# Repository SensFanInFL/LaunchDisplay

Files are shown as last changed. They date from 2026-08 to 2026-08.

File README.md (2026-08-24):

# LaunchDisplay

LaunchDisplay is a Wi-Fi-connected ESP32-C3 launch countdown device for a 320x480 SPI TFT display. It shows the next relevant rocket launch, counts down to liftoff, tracks post-launch T+ behavior, and can be configured entirely from its built-in web setup pages.

## What It Does

- Boots on a TENSTAR ESP32-C3-Zero board and drives an Estardyn 3.5" 320x480 ST7796S SPI TFT
- Connects to Wi-Fi using a first-run onboarding portal
- Lets you configure launch filtering, timezone, sleep schedule, and level of Space Devs API access from the browser
- Shows the next launch with:
  - rocket name
  - mission or launch name
  - launch site and pad
  - scheduled date and time
  - large countdown
  - authoritative launch status
- Supports both free and paid Space Devs accounts
- Adapts polling frequency to stay within the selected account tier
- Uses a sleep schedule so the display can go dark during chosen hours

## Hardware

Verified hardware:

- Board: TENSTAR ESP32-C3-Zero
- Display: Estardyn 3.5" 320x480 ST7796S SPI TFT
- Power: USB
- Library: LovyanGFX

## Wiring

Current verified wiring:

| TFT | ESP32-C3 |
| --- | --- |
| GND | GND |
| VCC | 5V |
| SCL / SCLK | GPIO4 |
| SDA / MOSI | GPIO6 |
| RST | GPIO0 |
| DC | GPIO1 |
| CS | GPIO7 |
| BL | GPIO5 |

## STL files

STL files are in the STL directory, along with information on assembling the case.

## Display Behavior

### Normal launch view

When the device is connected and polling successfully, the screen shows:

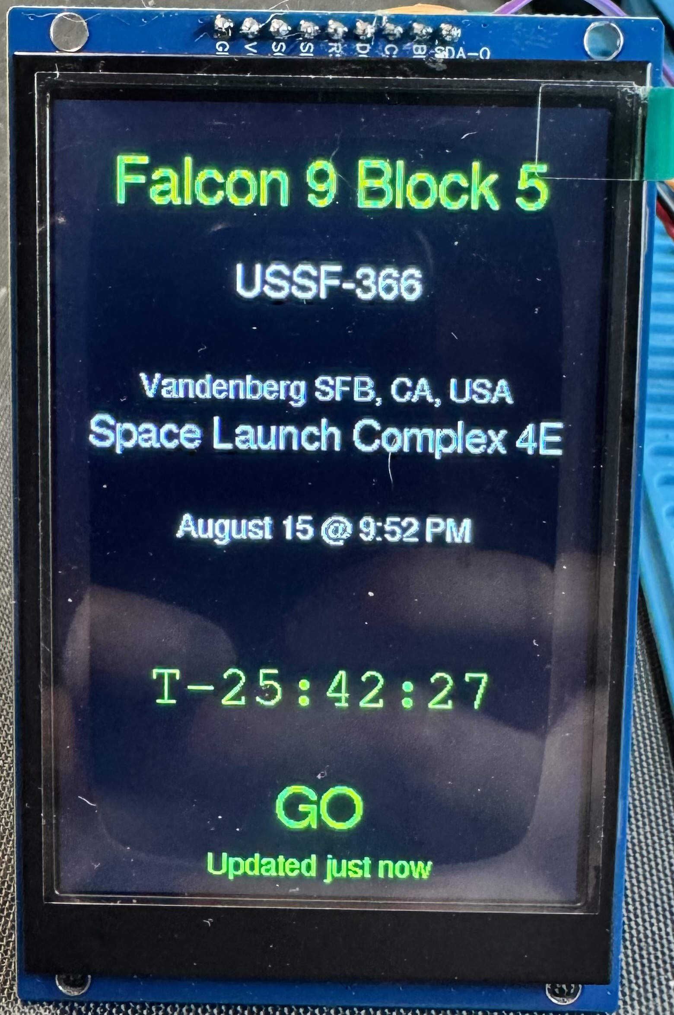
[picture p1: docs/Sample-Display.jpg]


- rocket
- mission name
- launch site
- pad
- scheduled date/time
- countdown timer
- launch status such as GO, HOLD, DELAYED, SCRUBBED, LAUNCHED, or RUD

### Startup and setup states

- If Wi-Fi is not configured yet, the device starts a setup portal named `LaunchDisplay-Setup`
- The TFT shows a QR-based setup screen during initial onboarding
- If no launch data is available yet, the display shows a standby or waiting screen
- If live fetching fails, the screen switches to an error view instead of pretending the data is current

## Getting Started

### 1. Flash the firmware

Build and flash the project with PlatformIO.

### 2. Power the device

On first boot, LaunchDisplay will try to join the saved Wi-Fi.

### 3. If Wi-Fi is not saved

The device creates a setup access point:

- SSID: `LaunchDisplay-Setup`

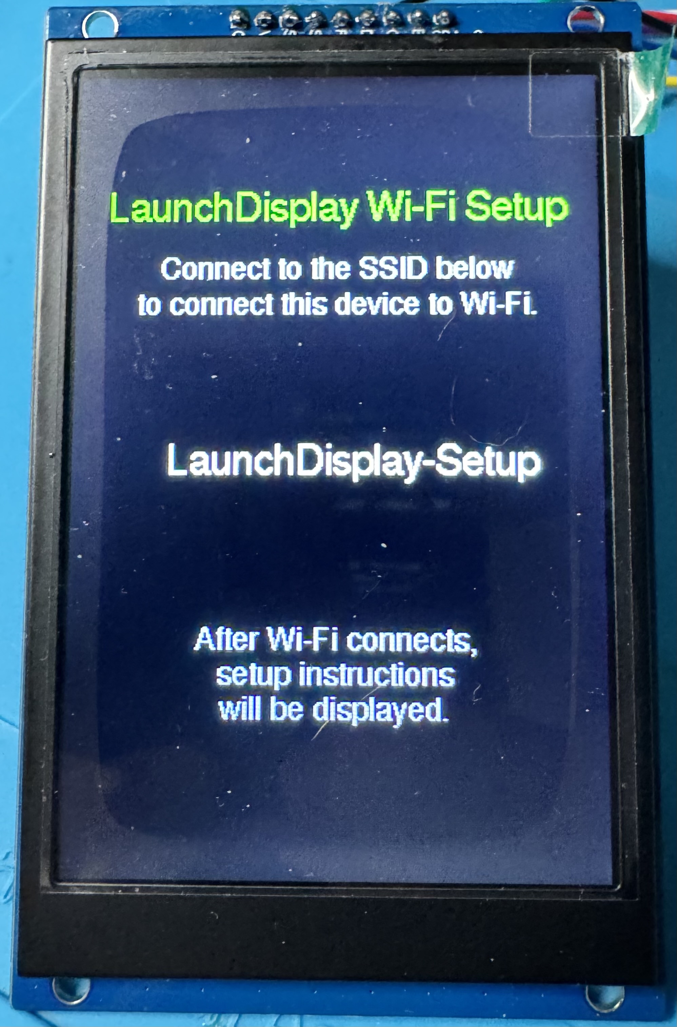
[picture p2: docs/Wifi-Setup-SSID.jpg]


- Once connected to the setup SSID, on most devices the wifi setup screen will appear on a captive portal screen. If this does not happen on your device, open a connection to http://192.168.4.1. 

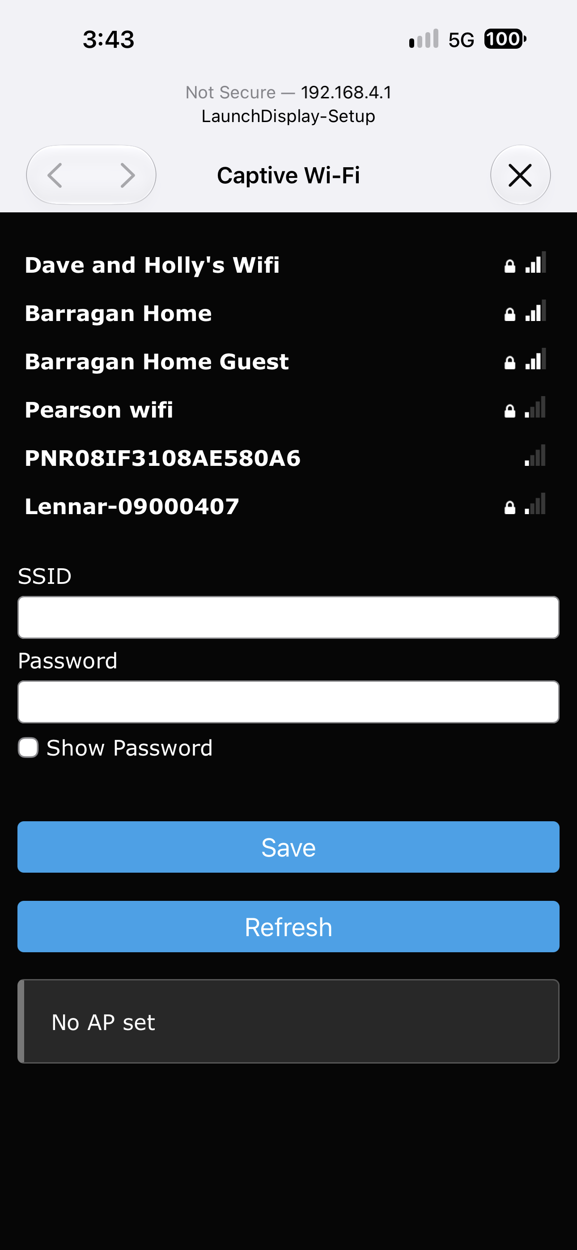
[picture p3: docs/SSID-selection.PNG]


- Select the wifi SSID you wish to connect to and enter the pre-shared key for that network. 

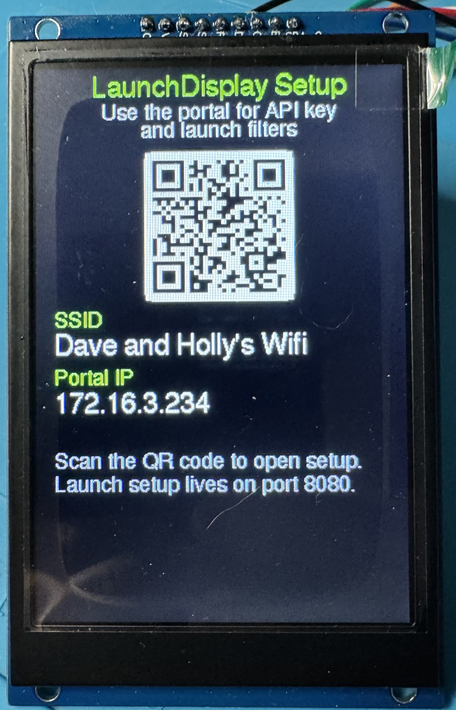
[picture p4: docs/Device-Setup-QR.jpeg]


- After the device has successfully connected to wifi, the initial setup screen is displayed. You can either scan the QR code or manually open a http connection on port 8080 to the IP address displayed on the screen to navigate to the setup portal. For example, in the pic above you would go to http://172.16.3.234:8080

### 4. Open the web setup pages

If you scan the QR code during the initial setup, you should go directly to the setup page. However, if you bookmark the setup page, you can always come back to it for access to the following options:

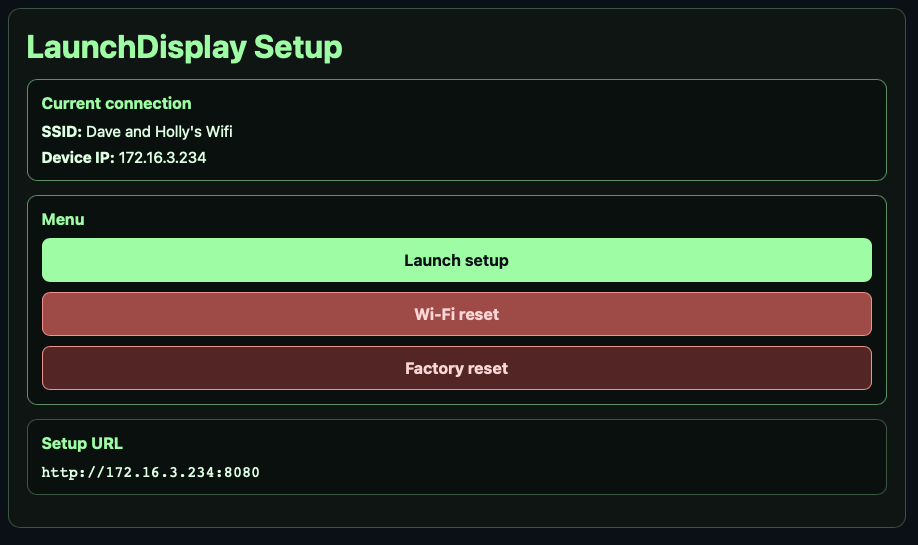
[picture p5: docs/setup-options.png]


- Settings
- Wi-Fi reset
- Factory reset

## Setup Pages

The main menu is served from the device on port `8080`.

The launch settings page is where you configure everything about what LaunchDisplay should follow and how it should behave.

## Setup Options

### API access

LaunchDisplay defaults to the free version of The Space Devs API. 

Users that have a paid membership to The Space Devs should click the box for "I have a paid Space Devs membership" to access the following additional settings:

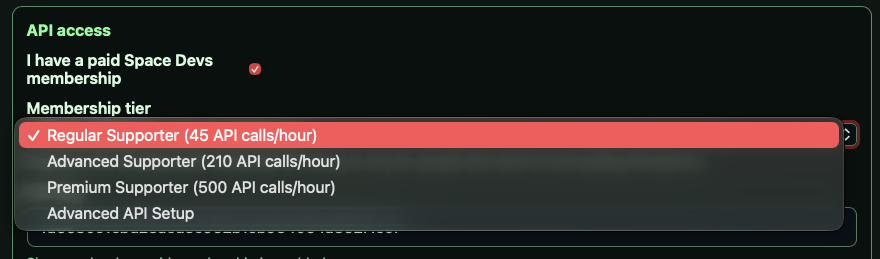
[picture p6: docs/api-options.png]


| Setting | What it does | Notes |
| --- | --- | --- |
| I have a paid Space Devs membership | Enables the paid-account path | Leave unchecked for free tier use |
| Membership tier | Chooses the paid polling model | Regular Supporter, Advanced Supporter, Premium Supporter, or Advanced API Setup |
| API key | Space Devs API key | Required for paid membership modes |

### Manually specifying polling frequency

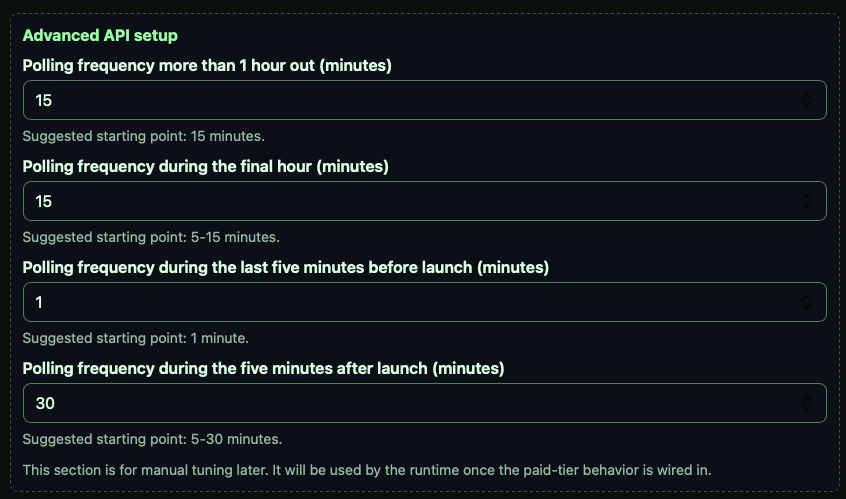
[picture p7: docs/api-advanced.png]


These fields appear when you choose `Advanced API Setup`:

| Setting | What it does | Notes |
| --- | --- | --- |
| Polling frequency more than 1 hour out (minutes) | Poll interval far from launch | Suggested starting point: 15 |
| Polling frequency during the final hour (minutes) | Poll interval closer to launch | Suggested starting point: 5-15 |
| Polling frequency during the last five minutes before launch (minutes) | Final pre-launch polling interval | Suggested starting point: 1 |
| Polling frequency during the five minutes after launch (minutes) | Early post-launch polling interval | Suggested starting point: 5-30 |

### Launch scope

| Setting | What it does | Notes |
| --- | --- | --- |
| Launch scope | Chooses the scope filter | Within a distance, Country, or Worldwide |
| Worldwide (default value) | Shows all schedule launches | No filters applied |
| Country | Filters launches by country | Used only when Launch scope is Country |
| LaunchDisplay Location | Reference location for distance-based scope | Use a city or place name, not a street address or coordinates |
| Distance units | Miles or kilometers | Used only when Launch scope is Within a distance |
| Distance | Distance from the specified location | Used only when Launch scope is Within a distance |





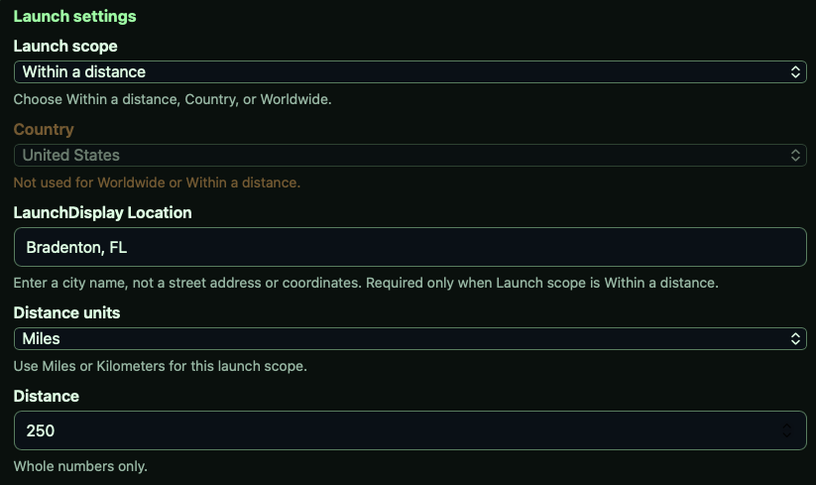
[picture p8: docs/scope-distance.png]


### Time and schedule

| Setting | What it does | Notes |
| --- | --- | --- |
| Time Zone | Display timezone | Used for launch time formatting and countdown behavior |
| Post-launch rollover | How long to keep showing T+ after launch | 15 minutes, 30 minutes, 1 hour, or 2 hours |





### Sleep schedule

| Setting | What it does | Notes |
| --- | --- | --- |
| Enable schedule | Turns scheduled sleep on or off | When enabled, the TFT sleeps during the chosen window |
| Sleep starts | Sleep start time | Time picker |
| Sleep ends | Sleep end time | Time picker |

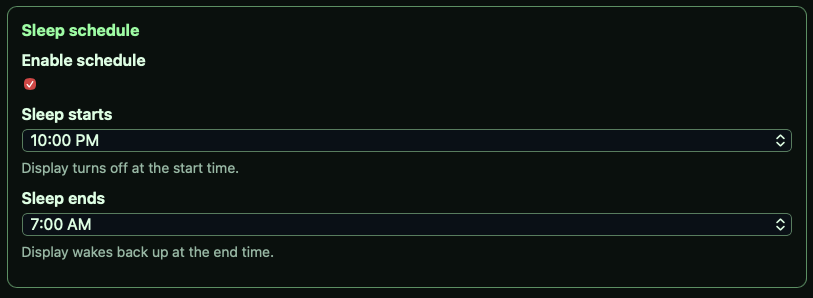
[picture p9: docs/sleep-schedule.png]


## Polling Behavior

LaunchDisplay intentionally changes how often it polls depending on how close the launch is.

The goal is to:

- stay within the account tier limits
- poll more often when launch time is near
- back off after launch
- avoid hammering the API with unnecessary requests

If the API returns a rate-limit or transient network error, the device backs off and tries again later.

## Launch Data

LaunchDisplay uses Space Devs Launch Library data to determine the next launch.

The display is built around the idea that the data on-screen should be authoritative:

- scheduled launch time comes from the API
- T-minus counts down to that launch time
- after launch, the device can show T+ for a configurable rollover period
- if a launch later changes to HOLD, DELAYED, SCRUBBED, or RUD, the screen should reflect that instead of pretending the launch happened

## Troubleshooting

### The SSID does not appear

- Make sure the ESP32 is powered and booting
- Check the serial console for the Wi-Fi setup portal message
- If you recently changed Wi-Fi settings, confirm the device restarted cleanly

### The setup page keeps coming back

- Check whether the device is still unconfigured
- Verify that Wi-Fi settings were saved successfully
- Clear browser autofill or try a private window if the browser is restoring old form state

### The display is blank or inverted

- Re-check the TFT wiring against the wiring table
- Confirm the backlight pin is connected correctly
- Verify that the display type in `include/DisplayConfig.h` matches the actual panel

### The screen shows a fetch error

- Check Wi-Fi
- Check the API key if you are on a paid tier
- Watch for rate-limit messages in the serial log
- If the API is temporarily overloaded or rate-limited, wait and try again

### The countdown looks wrong

- Confirm the timezone setting
- Confirm the launch scope
- Confirm that the launch data being shown is the correct filtered result for your location and account tier

## Development Notes

- Settings are stored on-device and do not require reflashing for normal configuration changes
- The display and web setup are intentionally separated so launch selection can be changed without touching the firmware
- The firmware keeps a simple appliance-style workflow: flash once, configure from the browser, then use it like a product

## License

MIT

## Roadmap

Keep in mind that not all ESP32's are the same dimensions as the one I used, so you will most likely need to adjust things to hold your ESP32 properly.

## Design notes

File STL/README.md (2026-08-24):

STLs are oriented for printing. 

## Recommended print settings:
- 3 walls
- 3 layers top and bottom
- 20% infill
- Organic/tree supports

## Hardware needed
- (4) M3 threaded inserts
- (4) M3x6 screws. Cap head screws look nice on it
- (4) M2.5x8 screws
- (4) M2.5 nuts

## How to assemble
### Step 1

Install the threaded inserts into the holes for them on the back

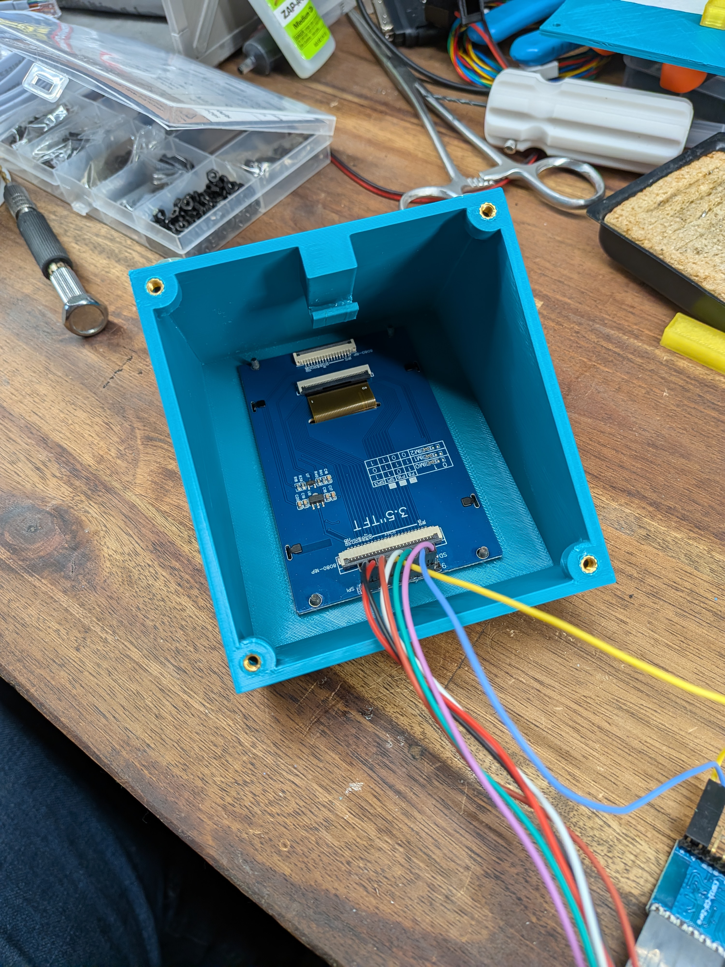
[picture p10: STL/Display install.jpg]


Glue the bracket to the ESP32 holder as shown. Cyanoacrylate glue will work fine. 

- Note: the bracket supplied in the STLs is properly sized. Glue the long side of the bracket to the ESP32 holder, butted against the bottom.
- The bracket should set approximately 3mm above the top side of the ESP32 holder.

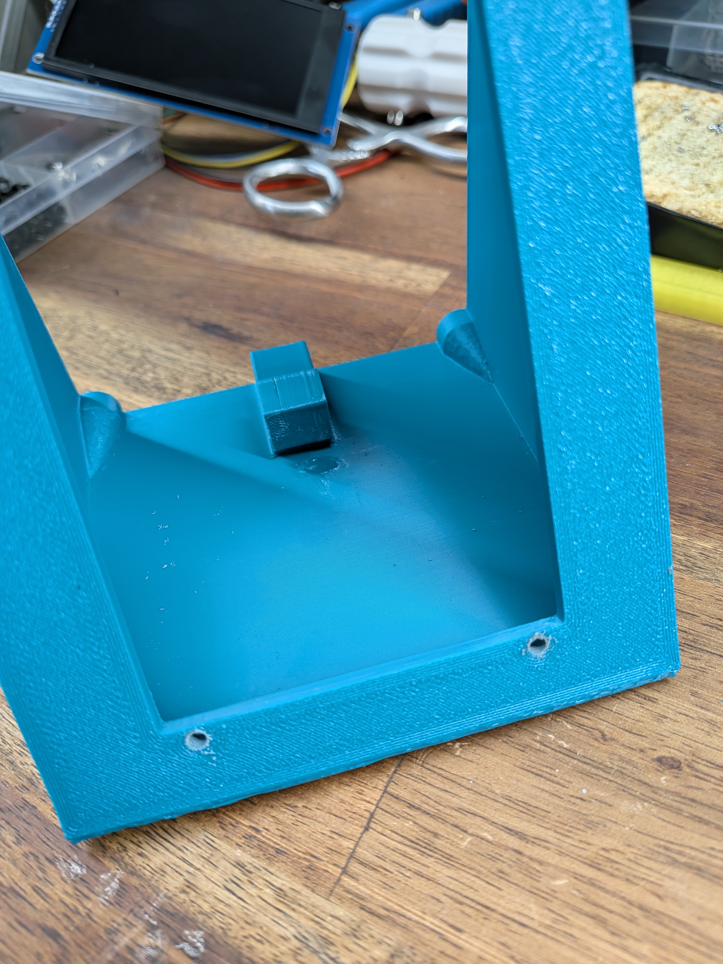
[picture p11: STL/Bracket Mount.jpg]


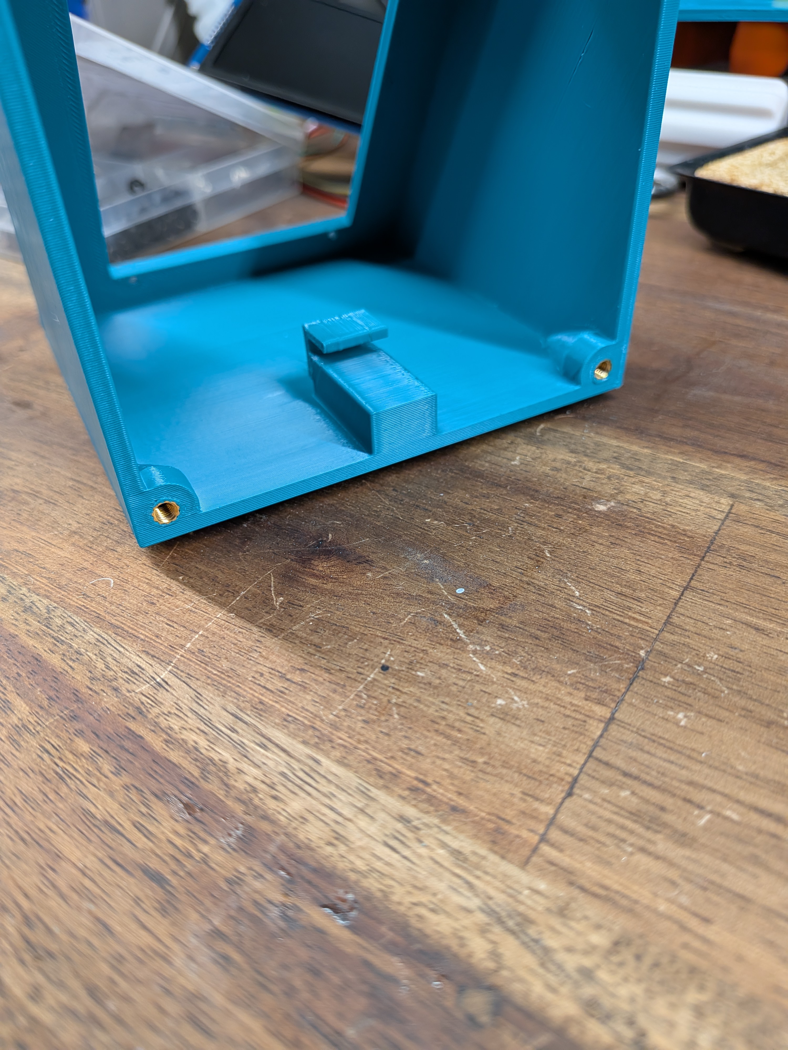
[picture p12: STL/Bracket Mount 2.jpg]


Depending on printer tolerance, you may need to drill the holes around the display opening out to 2.5mm

Install the M2.5x8 screws and install the display using the M2.5 nuts.
* The wrench STL supplied is sized such that you should be able to insert the nut, set it on the bottom of the case and slide it in to help with installing the lower nuts. You can do them by hand, but they're difficult to install.



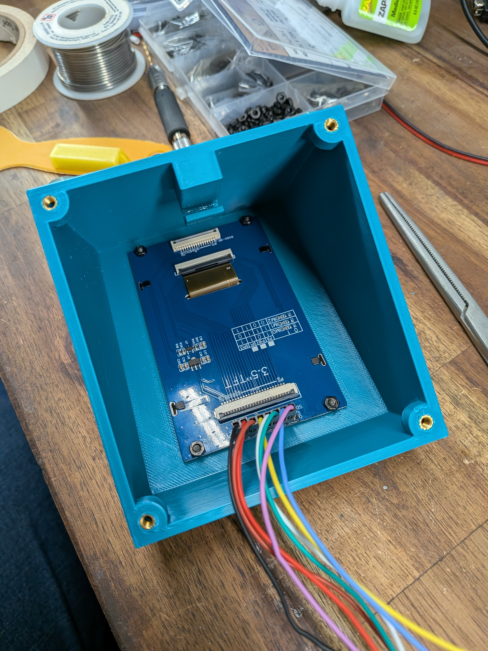
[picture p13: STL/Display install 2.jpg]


Place the ESP32 controller on the holder, with the rear of the ESP32 under the bracket that you installed earlier. The bracket keeps the rear of the controller in place, and works with the nubs on the back panel to position it such that the power cable can be plugged into it.

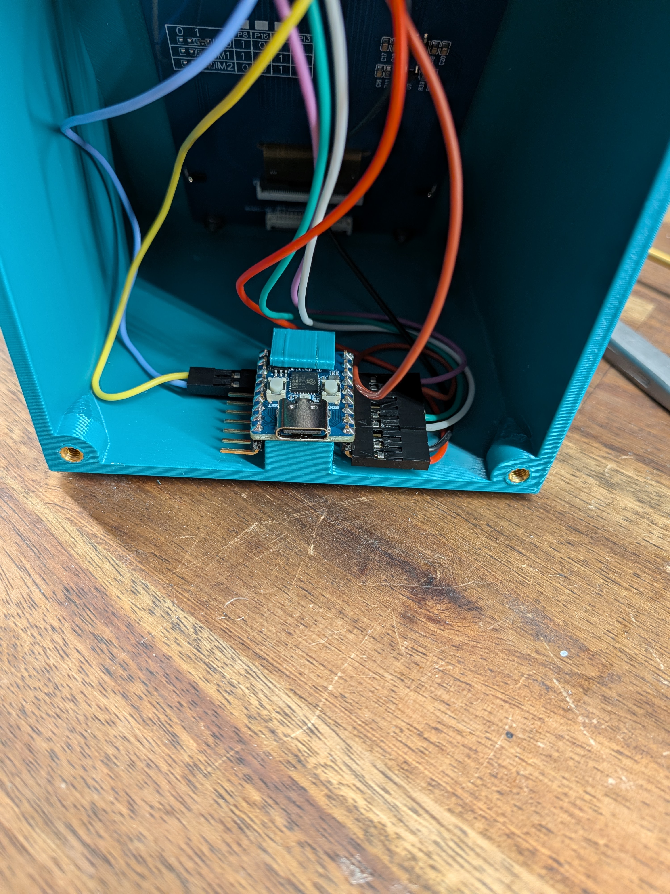
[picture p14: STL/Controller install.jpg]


Finally, install the back panel with the M3x6 screws

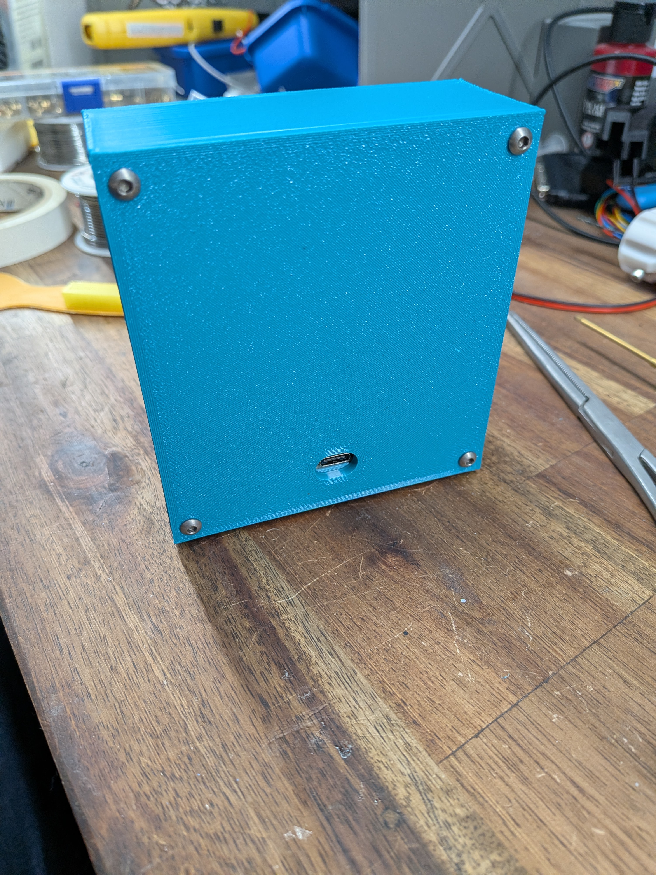
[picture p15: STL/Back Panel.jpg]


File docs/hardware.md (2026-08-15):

# LaunchDisplay Hardware Notes

This note captures the verified hardware combination for the current LaunchDisplay bring-up.

## Verified Setup

- Board: TENSTAR ESP32-C3-Zero Mini Development Board
- MCU: ESP32-C3
- Display: Estardyn 3.5" 320x480 ST7796S SPI TFT module
- Display library: LovyanGFX
- Power: USB

## Working Pin Map

| TENSTAR ESP32-C3-Zero Mini | TFT |
| --- | --- |
| `GPIO4` | `SCL` / `SCLK` |
| `GPIO6` | `SDA` / `MOSI` |
| `GPIO7` | `CS` |
| `GPIO1` | `DC` |
| `GPIO0` | `RST` |
| `GPIO5` | `BL` |
| `5V` | `VCC` |
| `GND` | `GND` |

## Notes

- `GPIO2`, `GPIO8`, and `GPIO9` are strapping pins on the ESP32-C3, so they are left unused.
- `GPIO18` and `GPIO19` are associated with USB serial/JTAG on the C3 family, so they are also left unused.
- `GPIO20` and `GPIO21` are left free so the default serial path stays simple.

## Wiring diagrams

- [`docs/wiring-schematic.svg`](./wiring-schematic.svg)
- [`docs/wiring-breadboard.svg`](./wiring-breadboard.svg)

## Bring-Up Result

The current firmware successfully:

- connects to Wi-Fi using the reused setup flow,
- initializes the TFT display,
- and renders the LaunchDisplay standby / launch screen.

That makes this a verified baseline for future launch data integration work.

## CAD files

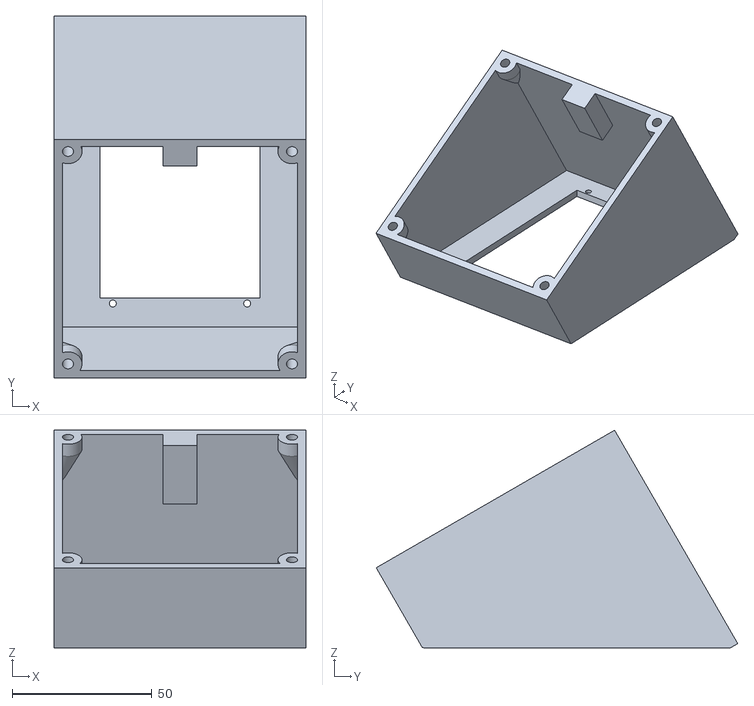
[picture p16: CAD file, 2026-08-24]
STL/Body.stl
90.0 x 129.1 x 77.7

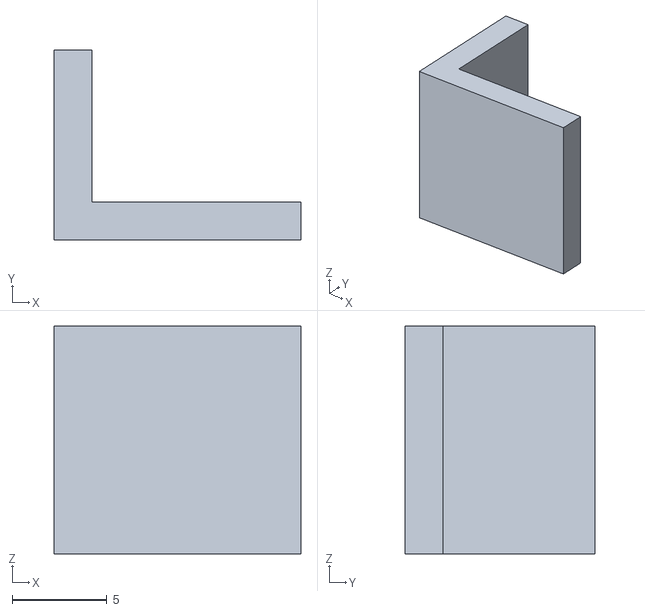
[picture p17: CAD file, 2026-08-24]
STL/Bracket.stl
13.0 x 10.0 x 12.0

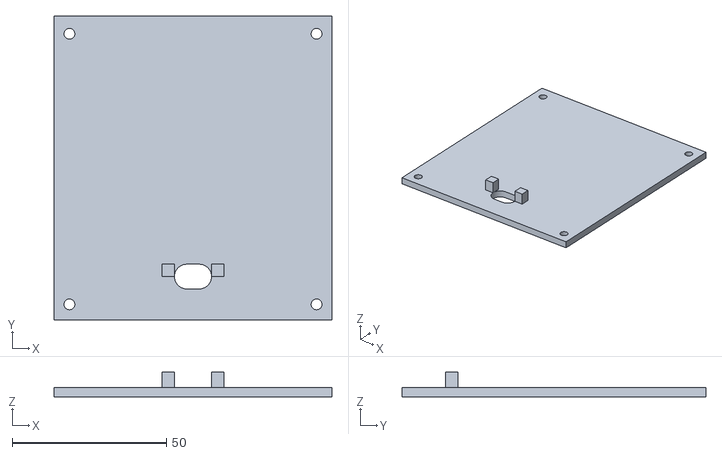
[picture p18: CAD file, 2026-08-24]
STL/Back Panel.stl
90.0 x 98.3 x 8.00

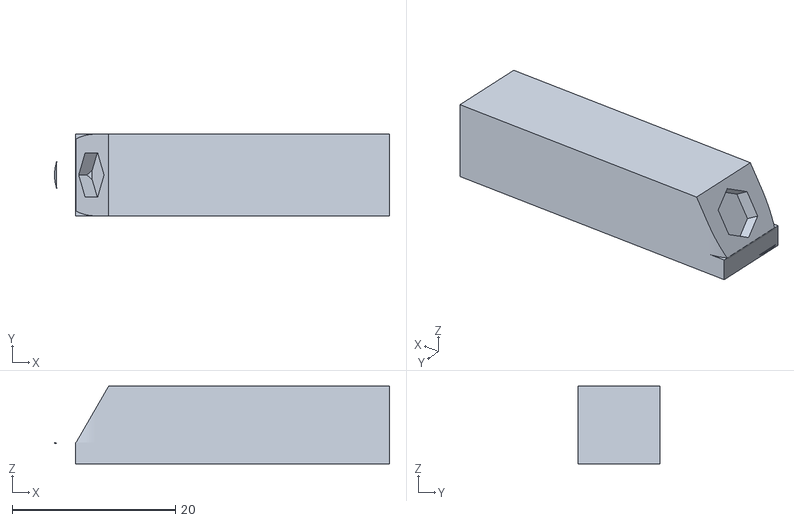
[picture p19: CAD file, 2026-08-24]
STL/Wrench.stl
41.0 x 10.0 x 9.50

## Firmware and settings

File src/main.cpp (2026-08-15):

#include <Arduino.h>
#include <array>
#include <time.h>
#include <WiFi.h>
#include <WiFiManager.h>
#include <WebServer.h>

#include "DisplayConfig.h"
#include "LGFX.h"
#include "LaunchDisplayApp.h"
#include "LaunchLibraryClient.h"
#include "LaunchSettings.h"
#include "WiFiManagerHelpers.h"

static void LoadSleepSchedule(const LaunchSettings &settings);

enum class LaunchScreenMode
{
  Setup,
  Preview,
};

extern LaunchScreenMode screenMode;
extern bool screenNeedsRedraw;
extern LaunchLibraryClient launchLibraryClient;

namespace
{
struct LaunchPollState
{
  LaunchPreviewState preview;
  bool hasPreview = false;
  unsigned long nextPollAtMs = 0;
  std::array<unsigned long, 15> pollHistory{};
  size_t pollHistoryCount = 0;
  String lastError;
};

LaunchPollState launchPollState;
bool pendingScopeVerification = false;
LaunchSettings activeSettings;
bool displaySleeping = false;
int sleepStartMinutes = 22 * 60;
int sleepEndMinutes = 7 * 60;
bool sleepScheduleEnabled = false;

struct SelectOption
{
  const char *value;
  const char *label;
};

constexpr SelectOption kLaunchScopeOptions[] = {
    {"within_distance", "Within a distance"},
    {"country", "Country"},
    {"worldwide", "Worldwide"},
};

constexpr SelectOption kDistanceUnitOptions[] = {
    {"miles", "Miles"},
    {"kilometers", "Kilometers"},
};

constexpr SelectOption kPostLaunchOptions[] = {
    {"15 minutes", "15 minutes"},
    {"30 minutes", "30 minutes"},
    {"1 hour", "1 hour"},
    {"2 hours", "2 hours"},
};

constexpr SelectOption kApiTierOptions[] = {
    {"regular_supporter", "Regular Supporter (45 API calls/hour)"},
    {"advanced_supporter", "Advanced Supporter (210 API calls/hour)"},
    {"premium_supporter", "Premium Supporter (500 API calls/hour)"},
    {"advanced_api_setup", "Advanced API Setup"},
};

constexpr SelectOption kSleepTimeOptions[] = {
    {"21:00", "9:00 PM"},
    {"22:00", "10:00 PM"},
    {"23:00", "11:00 PM"},
    {"00:00", "12:00 AM"},
    {"01:00", "1:00 AM"},
    {"06:00", "6:00 AM"},
    {"07:00", "7:00 AM"},
    {"08:00", "8:00 AM"},
};

constexpr SelectOption kCountryOptions[] = {
    {"United States", "United States"},
    {"Canada", "Canada"},
    {"Mexico", "Mexico"},
    {"United Kingdom", "United Kingdom"},
    {"Brazil", "Brazil"},
    {"Spain", "Spain"},
    {"France", "France"},
    {"Germany", "Germany"},
    {"Italy", "Italy"},
    {"Australia", "Australia"},
    {"Japan", "Japan"},
    {"New Zealand", "New Zealand"},
};

constexpr SelectOption kTimeZoneOptions[] = {
    {"UTC", "UTC"},
    {"America/New_York", "America/New_York"},
    {"America/Chicago", "America/Chicago"},
    {"America/Denver", "America/Denver"},
    {"America/Los_Angeles", "America/Los_Angeles"},
    {"America/Phoenix", "America/Phoenix"},
    {"Europe/London", "Europe/London"},
    {"Europe/Paris", "Europe/Paris"},
    {"Asia/Tokyo", "Asia/Tokyo"},
    {"Australia/Sydney", "Australia/Sydney"},
};

String HtmlEscape(const String &input)
{
  String output;
  output.reserve(input.length() + 8);
  for (size_t i = 0; i < input.length(); ++i)
  {
    const char c = input[i];
    switch (c)
    {
    case '&':
      output += F("&amp;");
      break;
    case '<':
      output += F("&lt;");
      break;
    case '>':
      output += F("&gt;");
      break;
    case '"':
      output += F("&quot;");
      break;
    case '\'':
      output += F("&#39;");
      break;
    default:
      output += c;
      break;
    }
  }
  return output;
}

String RenderSelectOptions(const String &currentValue, const SelectOption *options, size_t optionCount)
{
  String html;
  bool matched = false;
  for (size_t i = 0; i < optionCount; ++i)
  {
    if (currentValue == options[i].value)
    {
      matched = true;
      break;
    }
  }

  if (!matched && currentValue.length())
  {
    html += F("<option value='");
    html += HtmlEscape(currentValue);
    html += F("' selected>");
    html += HtmlEscape(currentValue);
    html += F("</option>");
  }

  for (size_t i = 0; i < optionCount; ++i)
  {
    html += F("<option value='");
    html += HtmlEscape(options[i].value);
    html += F("'");
    if (currentValue == options[i].value)
    {
      html += F(" selected");
    }
    html += F(">");
    html += HtmlEscape(options[i].label);
    html += F("</option>");
  }

  return html;
}

String RenderSelectField(const char *name, const char *label, const String &currentValue, const SelectOption *options, size_t optionCount, const String &hint = String())
{
  String html;
  html += F("<label class='field'>");
  html += F("<span>");
  html += HtmlEscape(label);
  html += F("</span>");
  html += F("<select name='");
  html += HtmlEscape(name);
  html += F("'>");
  html += RenderSelectOptions(currentValue, options, optionCount);
  html += F("</select>");
  if (hint.length())
  {
    html += F("<div class='hint'>");
    html += HtmlEscape(hint);
    html += F("</div>");
  }
  html += F("</label>");
  return html;
}

String RenderTextField(const char *name, const char *label, const String &value, const char *placeholder, const String &hint = String())
{
  String html;
  html += F("<label class='field'>");
  html += F("<span>");
  html += HtmlEscape(label);
  html += F("</span>");
  html += F("<input name='");
  html += HtmlEscape(name);
  html += F("' type='text' value='");
  html += HtmlEscape(value);
  html += F("' placeholder='");
  html += HtmlEscape(placeholder);
  html += F("'>");
  if (hint.length())
  {
    html += F("<div class='hint'>");
    html += HtmlEscape(hint);
    html += F("</div>");
  }
  html += F("</label>");
  return html;
}

String RenderTimeField(const char *name, const char *label, const String &value, const String &hint = String())
{
  String html;
  html += F("<label class='field'>");
  html += F("<span>");
  html += HtmlEscape(label);
  html += F("</span>");
  html += F("<input name='");
  html += HtmlEscape(name);
  html += F("' type='time' value='");
  html += HtmlEscape(value);
  html += F("'>");
  if (hint.length())
  {
    html += F("<div class='hint'>");
    html += HtmlEscape(hint);
    html += F("</div>");
  }
  html += F("</label>");
  return html;
}

String RenderNumberField(const char *name, const char *label, const String &value, const char *minValue, const char *maxValue, const String &hint = String())
{
  String html;
  html += F("<label class='field'>");
  html += F("<span>");
  html += HtmlEscape(label);
  html += F("</span>");
  html += F("<input name='");
  html += HtmlEscape(name);
  html += F("' type='number' min='");
  html += HtmlEscape(minValue);
  html += F("' max='");
  html += HtmlEscape(maxValue);
  html += F("' value='");
  html += HtmlEscape(value);
  html += F("'>");
  if (hint.length())
  {
    html += F("<div class='hint'>");
    html += HtmlEscape(hint);
    html += F("</div>");
  }
  html += F("</label>");
  return html;
}

String RenderCheckboxField(const char *name, const char *label, bool checked, const String &hint = String())
{
  String html;
  html += F("<label class='field inline'>");
  html += F("<span>");
  html += HtmlEscape(label);
  html += F("</span><input name='");
  html += HtmlEscape(name);
  html += F("' type='checkbox'");
  if (checked)
  {
    html += F(" checked");
  }
  html += F("></label>");
  if (hint.length())
  {
    html += F("<div class='hint'>");
    html += HtmlEscape(hint);
    html += F("</div>");
  }
  return html;
}

String BuildSetupPage(const LaunchSettings &settings, const String &wifiSsid, const String &deviceIp, bool saved = false, const String &bannerMessage = String(), bool bannerIsError = false)
{
  const String setupUrl = String("http://") + deviceIp + ":8080/launch-setup";
  const bool wifiReady = wifiSsid.length() > 0 && deviceIp.length() > 0 && deviceIp != "0.0.0.0";
  const bool launchConfigured = settings.configured;

  String html;
  html.reserve(12000);
  html += F("<!doctype html><html><head><meta name='viewport' content='width=device-width, initial-scale=1'>");
  html += F("<title>LaunchDisplay Setup</title><style>");
  html += F("body{margin:0;padding:18px;background:#081017;color:#d6ffe1;font-family:system-ui,-apple-system,Segoe UI,Roboto,sans-serif;}");
  html += F("main{max-width:860px;margin:0 auto;border:1px solid #30543f;background:#0d1512;padding:18px;border-radius:12px;}");
  html += F("h1{margin:0 0 10px;font-size:2rem;color:#7cff9a;}");
  html += F(".section{border:1px solid #315844;background:#09100d;padding:14px;border-radius:10px;margin:14px 0;}");
  html += F(".section.green{border-color:#4b915f;}");
  html += F(".section.orange{border-color:#9a6b32;}");
  html += F(".section.red{border-color:#a44;}");
  html += F(".section-title{font-weight:700;color:#7cff9a;margin-bottom:10px;}");
  html += F(".section.orange .section-title{color:#ffb04c;}");
  html += F(".section.red .section-title{color:#ff8b8b;}");
  html += F(".field{display:flex;flex-direction:column;gap:6px;margin:12px 0;}");
  html += F(".field.inline{flex-direction:row;align-items:center;justify-content:space-between;gap:12px;}");
  html += F(".field span{font-weight:600;color:#d6ffe1;}");
  html += F(".field input,.field select{width:100%;box-sizing:border-box;background:#081017;color:#d6ffe1;border:1px solid #4d7d5b;padding:10px 12px;border-radius:8px;font-size:1rem;}");
  html += F(".field.dimmed{opacity:0.45;}");
  html += F(".field.active span{color:#7cff9a;}");
  html += F(".field.inactive span{color:#ffb04c;}");
  html += F(".hidden{display:none;}");
  html += F(".subsection{border:1px dashed #315844;background:#081017;padding:12px;border-radius:8px;margin:12px 0;}");
  html += F(".subsection-title{font-weight:700;color:#7cff9a;margin-bottom:8px;}");
  html += F(".hint{font-size:0.88rem;color:#90b9a3;line-height:1.35;}");
  html += F(".status{display:grid;grid-template-columns:1fr;gap:8px;font-size:0.95rem;color:#d6ffe1;}");
  html += F(".button-row{display:flex;flex-wrap:wrap;gap:10px;align-items:center;}");
  html += F(".button{display:inline-block;text-decoration:none;padding:10px 14px;border-radius:8px;border:1px solid #4d7d5b;background:#1d3f2d;color:#d6ffe1;font-weight:700;}");
  html += F(".button.danger{border-color:#a44;background:#432;}");
  html += F(".button.save{background:#7cff9a;color:#081017;border-color:#7cff9a;}");
  html += F(".divider{height:1px;background:#315844;margin:14px 0;}");
  html += F(".note{font-size:0.9rem;color:#90b9a3;line-height:1.4;}");
  html += F("code{background:#081017;padding:2px 6px;border-radius:6px;border:1px solid #315844;}");
  html += F("</style></head><body><main>");
  html += F("<h1>LaunchDisplay Setup</h1>");

  if (bannerMessage.length())
  {
    html += F("<div class='section ");
    html += bannerIsError ? F("red") : F("green");
    html += F("'><div class='section-title'>");
    html += bannerIsError ? F("Needs attention") : F("Verified");
    html += F("</div><div class='note'>");
    html += HtmlEscape(bannerMessage);
    html += F("</div></div>");
  }
  else if (saved)
  {
    html += F("<div class='section green'><div class='section-title'>Saved</div><div class='note'>Launch settings were saved successfully.</div></div>");
  }

  html += F("<div class='button-row'><a href='http://");
  html += HtmlEscape(deviceIp);
  html += F(":8080/' class='button' style='background:#1d3f2d;color:#d6ffe1;border:1px solid #4d7d5b'>Back To Main Menu</a></div>");

  html += F("<div class='section ");
  html += wifiReady ? F("green") : F("orange");
  html += F("'><div class='section-title'>Current connection</div><div class='status'>");
  html += F("<div><strong>SSID:</strong> ");
  html += wifiSsid.length() ? HtmlEscape(wifiSsid) : F("Not connected");
  html += F("</div><div><strong>Device IP:</strong> ");
  html += HtmlEscape(deviceIp);
  html += F("</div><div><strong>Setup URL:</strong> <code>");
  html += HtmlEscape(setupUrl);
  html += F("</code></div></div></div>");

  html += F("<form action='/launch-save' method='post' autocomplete='off'>");
  html += F("<div class='section ");
  html += settings.paidMembership ? F("green") : F("orange");
  html += F("' id='api-access-section'><div class='section-title'>API access</div>");
  html += F("<label class='field inline'><span>I have a paid Space Devs membership</span><input name='paid_membership' id='paid-membership' type='checkbox' autocomplete='off'");
  if (settings.paidMembership)
  {
    html += F(" checked");
  }
  html += F("></label>");
  html += F("<label class='field' id='api-tier-field'>");
  html += F("<span>Membership tier</span>");
  html += F("<select name='api_tier' id='api-tier'>");
  html += RenderSelectOptions(settings.apiAccessTier, kApiTierOptions, sizeof(kApiTierOptions) / sizeof(kApiTierOptions[0]));
  html += F("</select>");
  html += F("<div class='hint'>Regular is the simplest path. Advanced API Setup is only for people who want to tune polling themselves.</div>");
  html += F("</label>");
  html += F("<label class='field' id='api-key-field'>");
  html += F("<span>API key</span>");
  html += F("<input name='api_key' id='api-key' type='text' value='");
  html += HtmlEscape(settings.apiKey);
  html += F("' placeholder='Paste your Space Devs API key'>");
  html += F("<div class='hint'>Shown only when paid membership is enabled.</div>");
  html += F("</label>");
  html += F("<div class='subsection hidden' id='advanced-api-section'><div class='subsection-title'>Advanced API setup</div>");
  html += RenderNumberField("api_poll_far_out", "Polling frequency more than 1 hour out (minutes)", settings.apiPollFarOutMinutes, "1", "60", "Suggested starting point: 15 minutes.");
  html += RenderNumberField("api_poll_final_hour", "Polling frequency during the final hour (minutes)", settings.apiPollFinalHourMinutes, "1", "30", "Suggested starting point: 5-15 minutes.");
  html += RenderNumberField("api_poll_launch_window", "Polling frequency during the last five minutes before launch (minutes)", settings.apiPollLaunchWindowMinutes, "1", "10", "Suggested starting point: 1 minute.");
  html += RenderNumberField("api_poll_post_launch", "Polling frequency during the five minutes after launch (minutes)", settings.apiPollPostLaunchMinutes, "1", "60", "Suggested starting point: 5-30 minutes.");
  html += F("<div class='hint'>This section is for manual tuning later. It will be used by the runtime once the paid-tier behavior is wired in.</div></div>");
  html += F("<div class='section ");
  html += launchConfigured ? F("green") : F("orange");
  html += F("'><div class='section-title'>Launch settings</div>");
  html += RenderSelectField("launch_scope", "Launch scope", settings.launchScope, kLaunchScopeOptions, sizeof(kLaunchScopeOptions) / sizeof(kLaunchScopeOptions[0]), "Choose Within a distance, Country, or Worldwide.");
  html += F("<label class='field' id='country-field'>");
  html += F("<span>Country</span>");
  html += F("<select name='country' id='country-select'>");
  html += RenderSelectOptions(settings.country, kCountryOptions, sizeof(kCountryOptions) / sizeof(kCountryOptions[0]));
  html += F("</select>");
  html += F("<div class='hint' id='country-hint'>Use this when Launch scope is Country. Distance does not apply here.</div>");
  html += F("</label>");
  html += F("<label class='field' id='location-field'>");
  html += F("<span>LaunchDisplay Location</span>");
  html += F("<input name='scope_location' id='scope-location' type='text' value='");
  html += HtmlEscape(settings.scopeLocation);
  html += F("' placeholder='Starbase, Texas'>");
  html += F("<div class='hint' id='location-hint'>Enter a city name, not a street address or coordinates. We verify this before saving within-distance scope.</div>");
  html += F("</label>");
  html += F("<label class='field' id='distance-units-field'>");
  html += F("<span>Distance units</span>");
  html += F("<select name='scope_units' id='scope-units'>");
  html += RenderSelectOptions(settings.scopeUnits, kDistanceUnitOptions, sizeof(kDistanceUnitOptions) / sizeof(kDistanceUnitOptions[0]));
  html += F("</select>");
  html += F("<div class='hint' id='distance-units-hint'>Used only when Launch scope is Within a distance.</div>");
  html += F("</label>");
  html += F("<label class='field' id='distance-field'>");
  html += F("<span>Distance</span>");
  html += F("<input name='scope_radius' id='scope-radius' type='number' min='1' max='500' value='");
  html += HtmlEscape(settings.scopeRadius);
  html += F("' placeholder='250'>");
  html += F("<div class='hint' id='distance-hint'>Not used for Country or Worldwide.</div>");
  html += F("</label>");
  html += RenderSelectField("timezone", "Time Zone", settings.timeZone, kTimeZoneOptions, sizeof(kTimeZoneOptions) / sizeof(kTimeZoneOptions[0]), "Used for launch times and countdown display.");
  html += RenderSelectField("post_launch", "Post-launch rollover", settings.postLaunchPeriod, kPostLaunchOptions, sizeof(kPostLaunchOptions) / sizeof(kPostLaunchOptions[0]), "How long to keep showing T+ after launch.");
  html += F("<div class='section ");
  html += settings.sleepEnabled ? F("green") : F("orange");
  html += F("'><div class='section-title'>Sleep schedule</div>");
  html += F("<label class='field'><span>Enable schedule</span><input name='sleep_enabled' type='checkbox'");
  if (settings.sleepEnabled)
  {
    html += F(" checked");
  }
  html += F("></label>");
  html += RenderSelectField("sleep_start", "Sleep starts", settings.sleepStart, kSleepTimeOptions, sizeof(kSleepTimeOptions) / sizeof(kSleepTimeOptions[0]), "Display turns off at the start time.");
  html += RenderSelectField("sleep_end", "Sleep ends", settings.sleepEnd, kSleepTimeOptions, sizeof(kSleepTimeOptions) / sizeof(kSleepTimeOptions[0]), "Display wakes back up at the end time.");
  html += F("</div>");
  html += F("<div class='button-row'><button type='submit' class='button save'>Save</button></div>");
  html += F("</div></form>");
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
void loop()
{
  launchSetupServer.handleClient();
  ResolvePendingLaunchScope();
  ApplySleepState();
  UpdateLiveCountdown();
  TickLaunchPolling();
  if (screenNeedsRedraw)
  {
    RedrawMainTft();
    screenNeedsRedraw = false;
  }
  delay(10);
}

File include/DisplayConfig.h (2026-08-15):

#pragma once

#include <Arduino.h>

// TENSTAR ESP32-C3-Zero bring-up pins for the Estardyn 3.5" ST7796S SPI TFT.
// Keep these in one place so the wiring stays easy to verify against the board.
constexpr int TFT_PIN_SCLK = 4;
constexpr int TFT_PIN_MOSI = 6;
constexpr int TFT_PIN_CS = 7;
constexpr int TFT_PIN_DC = 1;
constexpr int TFT_PIN_RST = 0;
constexpr int TFT_PIN_BL = 5;
constexpr bool TFT_BL_ACTIVE_HIGH = true;

constexpr uint32_t SERIAL_BAUD = 115200;

constexpr int TFT_WIDTH = 320;
constexpr int TFT_HEIGHT = 480;

constexpr const char *LAUNCH_DISPLAY_NAME = "LaunchDisplay";
constexpr const char *LAUNCH_DISPLAY_WIFI_AP = "LaunchDisplay-Setup";

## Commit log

2026-08-24 Add files via upload
    Hardware needed:
    For mounting the front panel:
    (4) M2.5 x 8 screws
    (4) M2.5 nuts
    For mounting the back panel:
    (4) M3 x 6 screws
    (4) M3 threaded inserts
    You will need to use right angle headers on the ESP32 to have clearance to mount it.
    Make the wiring harness about six inches long (150mm) to have enough length to reach from the top of the display to the ESP32 when it is mounted.
    [Back Panel.stl, Body.stl, Bracket.stl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]
2026-08-24 Added assembly photos and creaded a How-To
    [Back Panel.stl, Body.stl, Bracket.stl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]
